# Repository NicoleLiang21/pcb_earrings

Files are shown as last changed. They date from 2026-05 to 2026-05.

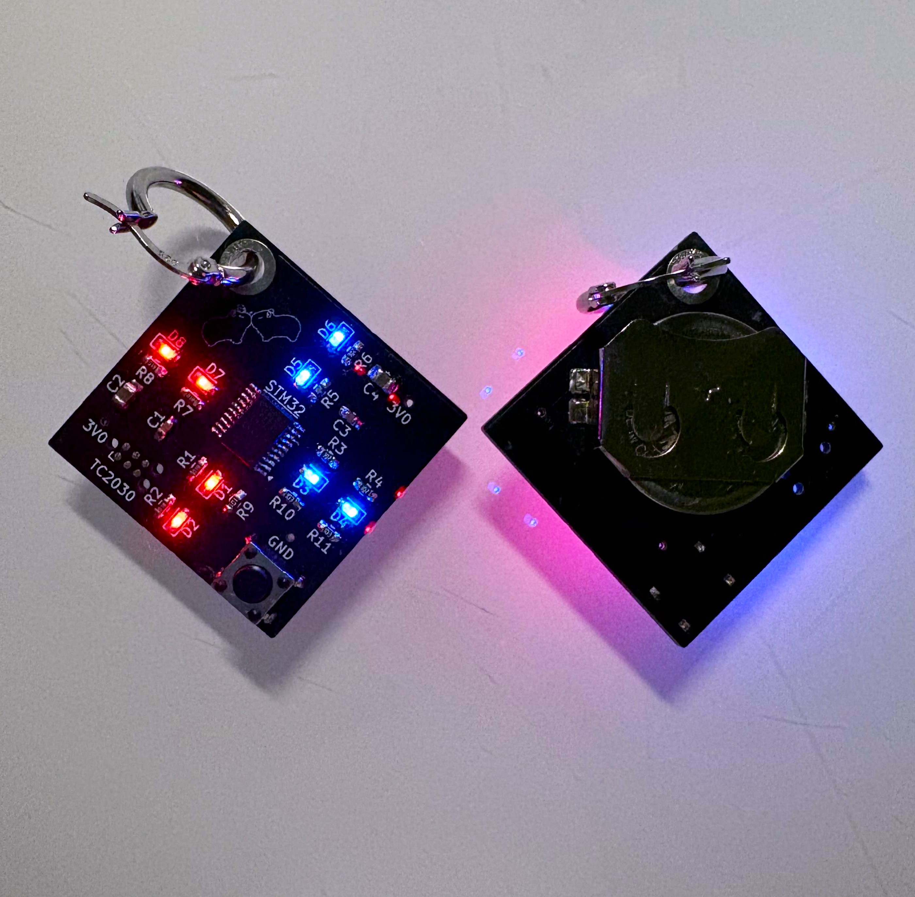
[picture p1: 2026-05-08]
hardware/media/photos/pcb_earrings.jpg

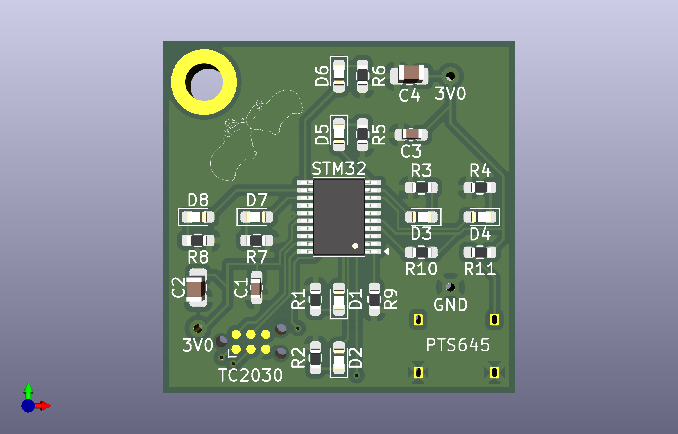
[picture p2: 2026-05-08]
hardware/media/exports/3D_render.png

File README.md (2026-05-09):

## PCB Earrings

### Overview

This project implements a wearable LED earring system built around an STM32 microcontroller, designed to drive LED lighting patterns on a custom PCB while maintaining constraints on size, power consumption, and wearability.

The hardware design focuses on balancing compact form factor, low-power operation, and visual appeal.

---

### System Architecture

The system consists of three primary subsystems:

- **Microcontroller (STM32)**  
  Handles LED sequencing, timing control, and GPIO-based output driving.

- **LED Array**  
  Radially arranged LEDs designed to create a myriad of different lighting effects.

- **Power System**  
  Low-voltage regulated supply designed for safe wearable operation and stable LED driving.

---

### PCB Design Constraints

The PCB was designed under the following constraints:

- Compact form factor suitable for wearable earrings  
- Radial symmetry for consistent visual aesthetics  
- Minimal trace length and optimized routing for small footprints  
- GPIO current limitations respected for direct LED driving  
- 3.0V logic compatibility with STM32 outputs  

These constraints directly influenced both component selection and board layout decisions.

---

### LED Current Design

LED current was calculated using Ohm’s law:

$$
I_{LED} = \frac{V_{CC} - V_f}{R}
$$

Where:
- $V_{CC}$ is the supply voltage (3.0V)
- $V_f$ is the LED forward voltage (~1.8–2.3V depending on component)
- $R$ is the current-limiting resistor

Initial (V1) and revised (V2) calculations were performed to refine resistor values and achieve the desired luminous intensities of the LEDs.

All supporting calculations are documented in `docs/calculations/`.

---

### Power Considerations

Power design priorities:

- Drive LEDs directly from GPIO within safe current limits  
- Limit peak current draw to extend battery life
- Conservative resistor sizing based on worst-case forward voltage  

These considerations ensure stable operation under battery-powered conditions.

---

### Bill of Materials (BOM)

A full Bill of Materials is included in `hardware/media/exports/`.

---

### Media

Additional photos, demonstrations, and project visuals are available on the project website:

[Project Website](NicoleLiang21.github.io)

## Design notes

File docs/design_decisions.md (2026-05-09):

## SMD Footprint Size

Revised design (v2) standardized the footprint of all surface mount devices to be 0603 [1608 Metric]. This change was implemented to increase the symmetricality of the board when worn to maximize visual appeal.

## LED Current Calculation Evolution

Initial design (v1) only considered the current passing through the red LED, and assigned the same resistor value to both the red and blue LEDs. Initial powering of the PCB revealed that the blue LEDs were much brighter than the red, and both colors of LEDs were too bright. After reviewing the LED datasheets, the resistor values were revised (v2) to reflect a more optimal operation point.

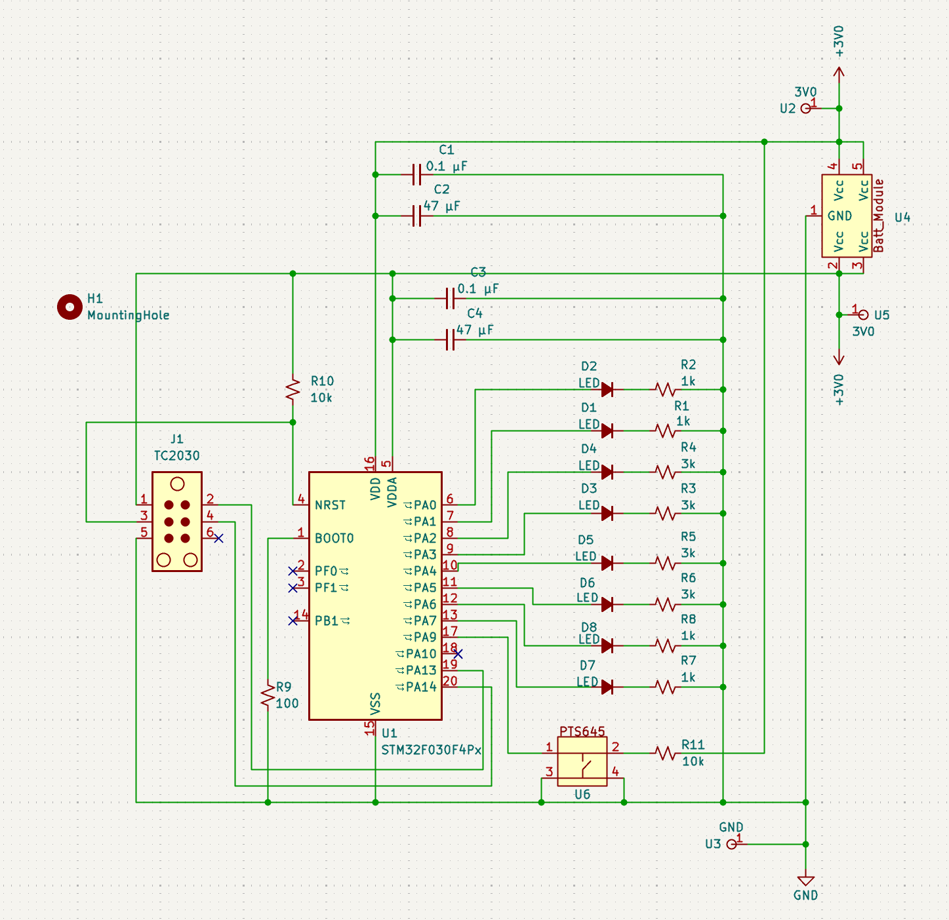
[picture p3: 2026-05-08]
hardware/media/exports/schematic.png

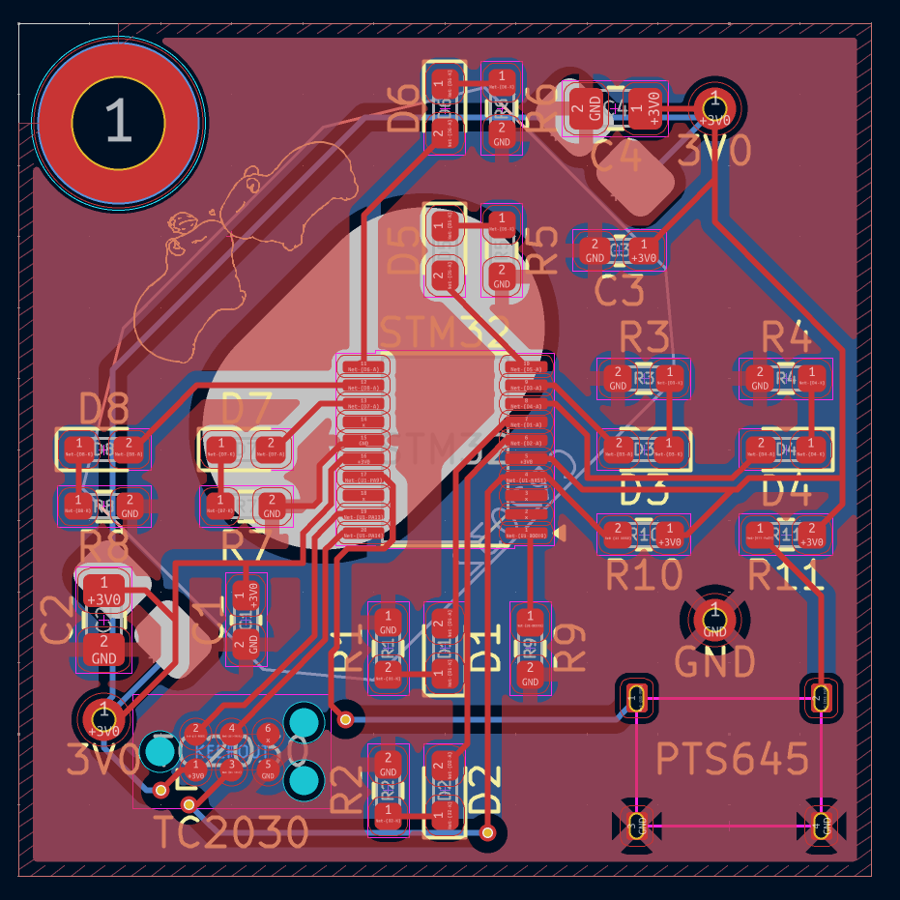
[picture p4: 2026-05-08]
hardware/media/exports/layout.png

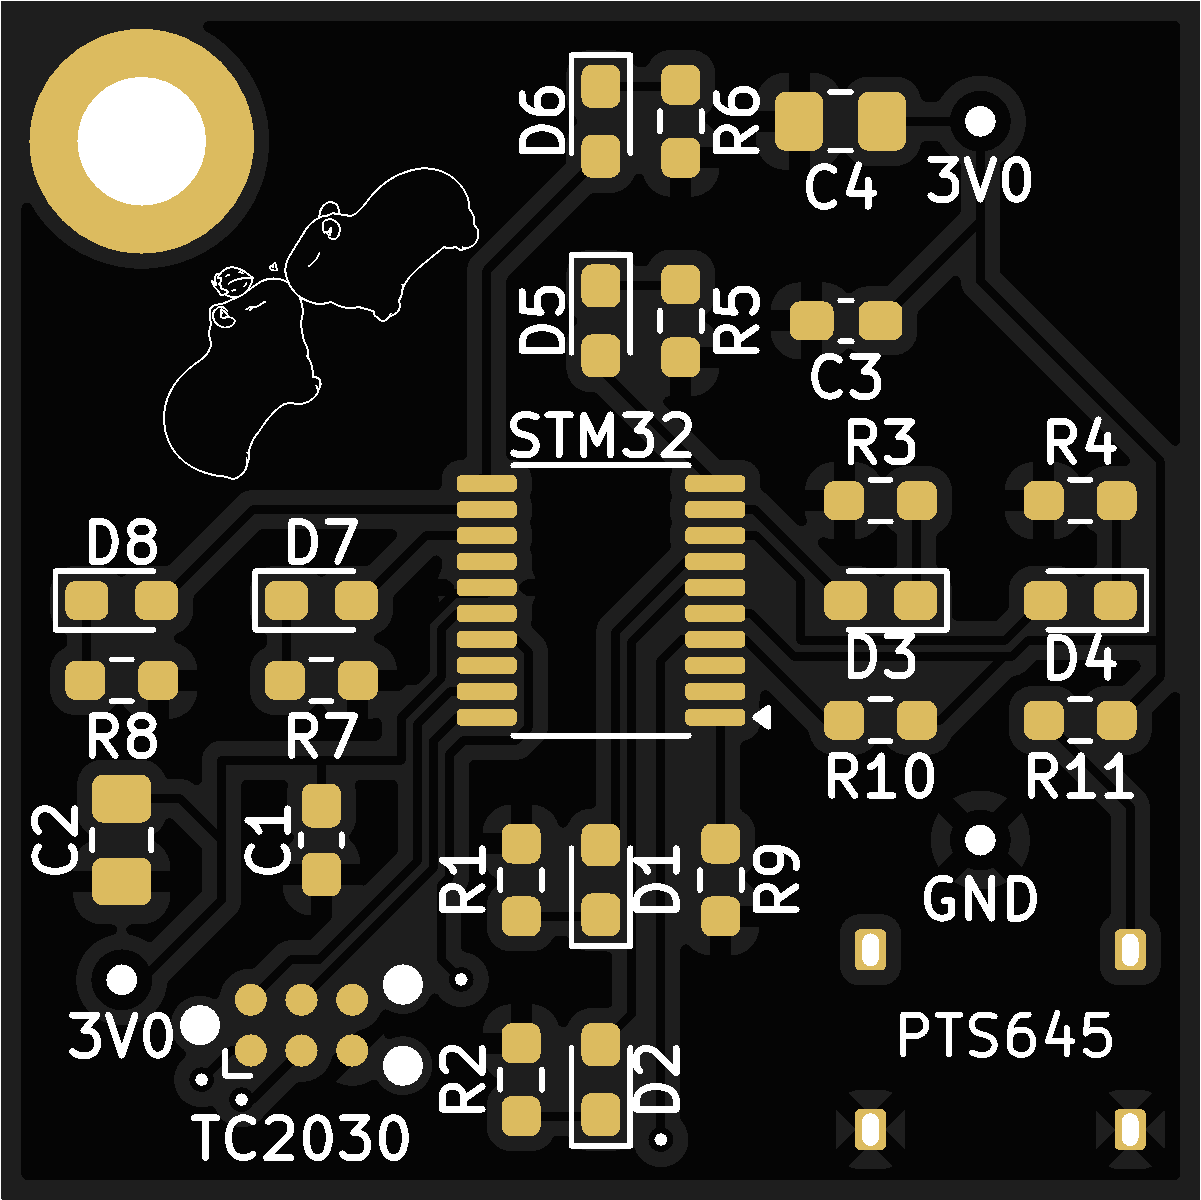
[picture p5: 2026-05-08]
hardware/media/exports/fab_preview.png

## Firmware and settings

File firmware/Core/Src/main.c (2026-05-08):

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
/* Includes ------------------------------------------------------------------*/
#include "main.h"

/* USER CODE BEGIN Includes */
#include <string.h>
/* USER CODE END Includes */

/* USER CODE BEGIN PD */
#define ON GPIO_PIN_SET
#define OFF GPIO_PIN_RESET
/* USER CODE END PD */


/* USER CODE BEGIN PV */
GPIO_TypeDef* PORT = GPIOA;
int LIGHT_STATE = 1; // Default to off state
volatile uint8_t buttonPressedFlag = 0;
/* USER CODE END PV */

void SystemClock_Config(void);
static void MX_GPIO_Init(void);
/**
  * @brief  The application entry point.
  * @retval int
  */
int main(void)
{

  /* MCU Configuration--------------------------------------------------------*/

  /* Reset of all peripherals, Initializes the Flash interface and the Systick. */
  HAL_Init();

  /* Configure the system clock */
  SystemClock_Config();

  /* Initialize all configured peripherals */
  MX_GPIO_Init();
  /* Infinite loop */
  /* USER CODE BEGIN WHILE */
  while (1)
  {
    /* USER CODE END WHILE */

    /* USER CODE BEGIN 3 */
	if (buttonPressedFlag) {
		buttonPressedFlag = 0;
	    LIGHT_STATE += 1;
	    LIGHT_STATE %= 4;
	    HAL_Delay(100);
	}

	// Allow button to toggle between states
	switch (LIGHT_STATE) {
		case 0:
			All(OFF);
			break;
		case 1:
			All(ON);
			break;
		case 2:
			Light_X("ripple");
			break;
		case 3:
			Light_X("charge");
		default:
			All(OFF);
			break;
	}

  }
  /* USER CODE END 3 */
}

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
/* USER CODE BEGIN 4 */

/**
 * Trigger an interrupt when the button is pressed. Used since animation functions are blocking
 * GPIO_Pin: the pin from which the signal is received
 */
void HAL_GPIO_EXTI_Callback(uint16_t GPIO_Pin)
{
	uint32_t lastPress = 0;
	const uint32_t debounce = 500; // Debounce time (ms)

    if  (GPIO_Pin == BUTTON_Pin) {
        if (HAL_GetTick() - lastPress >= debounce) {
        	lastPress = HAL_GetTick();
        	buttonPressedFlag = 1; // Mark button as pressed
        }
    }
}

/**
 * Turns all LEDs on/off depending on the given state
 * state: ON, OFF
 */
void All(GPIO_PinState state)
{
	uint16_t pins[] = {LED1_Pin, LED2_Pin, LED3_Pin, LED4_Pin, LED5_Pin, LED6_Pin, LED7_Pin, LED8_Pin};

	for (int i = 0; i < sizeof(pins)/sizeof(pins[0]); i++)
		HAL_GPIO_WritePin(PORT, pins[i], state);
}

/**
 * Blinks the LEDs in red/blue pairs from bottom to top
 */
void Light_X(char str[])
{
	uint16_t left[] = {LED2_Pin, LED1_Pin, LED7_Pin, LED8_Pin};
	uint16_t right[] = {LED4_Pin, LED3_Pin, LED5_Pin, LED6_Pin};
	int numLeft = sizeof(left)/sizeof(left[0]);
	int delay;
	int pause;

	if (strcmp(str, "ripple") == 0) {
		delay = 50;

		for (int i = 0; i < numLeft; i++) {
			// Toggle ON
			HAL_GPIO_TogglePin(PORT, left[i]);
			HAL_GPIO_TogglePin(PORT, right[i]);
			HAL_Delay(delay);

			// Toggle OFF
			HAL_GPIO_TogglePin(PORT, left[i]);
			HAL_GPIO_TogglePin(PORT, right[i]);
			HAL_Delay(delay);
		}
	}
	else if (strcmp(str, "charge") == 0) {
		delay = 100;
		pause = 1000;

		All(OFF);
		HAL_Delay(500);

		for (int i = 0; i < numLeft; i++) {
			HAL_GPIO_WritePin(PORT, left[i], ON);
			HAL_GPIO_WritePin(PORT, right[i], ON);
			HAL_Delay(delay);
		}
		HAL_Delay(pause);

		for (int i = numLeft-1; i >= 0; i--) {
			HAL_GPIO_WritePin(PORT, left[i], OFF);
			HAL_GPIO_WritePin(PORT, right[i], OFF);
			HAL_Delay(delay);
		}
	}

}
/* USER CODE END 4 */
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


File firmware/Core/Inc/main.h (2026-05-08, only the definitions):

#define LED2_Pin GPIO_PIN_0
#define LED2_GPIO_Port GPIOA
#define LED1_Pin GPIO_PIN_1
#define LED1_GPIO_Port GPIOA
#define LED4_Pin GPIO_PIN_2
#define LED4_GPIO_Port GPIOA
#define LED3_Pin GPIO_PIN_3
#define LED3_GPIO_Port GPIOA
#define LED5_Pin GPIO_PIN_4
#define LED5_GPIO_Port GPIOA
#define LED6_Pin GPIO_PIN_5
#define LED6_GPIO_Port GPIOA
#define LED8_Pin GPIO_PIN_6
#define LED8_GPIO_Port GPIOA
#define LED7_Pin GPIO_PIN_7
#define LED7_GPIO_Port GPIOA
#define BUTTON_Pin GPIO_PIN_9
#define BUTTON_GPIO_Port GPIOA
#define BUTTON_EXTI_IRQn EXTI4_15_IRQn

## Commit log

2026-05-08 Initial commit: LED earrings firmware migration to Github
2026-05-08 Add hardware files
    [capy_bara-B_Cu.gbr, capy_bara-B_Mask.gbr, capy_bara-B_Paste.gbr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]
2026-05-08 Remove irrelevant files, reorganize into fabrication/source files
    [capy_bara-B_Cu.gbr, capy_bara-B_Mask.gbr, capy_bara-B_Paste.gbr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]
2026-05-08 Add BOM

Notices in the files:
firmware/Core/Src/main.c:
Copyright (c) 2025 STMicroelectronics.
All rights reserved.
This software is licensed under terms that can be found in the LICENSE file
